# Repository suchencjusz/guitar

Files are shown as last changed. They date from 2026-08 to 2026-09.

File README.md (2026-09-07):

# guitar
My attempts on guitar effects! :D

### tremolo
Actually, the hardest parts were my first encounter with LTspice, and to be precise with ideal mathematical simulations;
as it turns out, building such a circuit with real components doesn't guarantee that it will actually work!
The next reality check came when I tried etching a PCB at home using sodium persulfate, the board turned out fine, but I'm not sure I'd take on that grueling manual task again if I were working with THT components.
The problem with my board was this: there was no ground-plane... It worked, but it picked up noise like the eye of Moscow in Pripyat... Oh, and on top of that, I placed the components incorrectly in KiCad.
I learned more about signal integrity on PCBs and how to do it better, so I redesigned the board and ordered it from a Chinese manufacturer.
After soldering, it worked right away it's never worked this well before. I think I've really learned my lesson about signal integrity on PCBs... the sound is crystal clear.

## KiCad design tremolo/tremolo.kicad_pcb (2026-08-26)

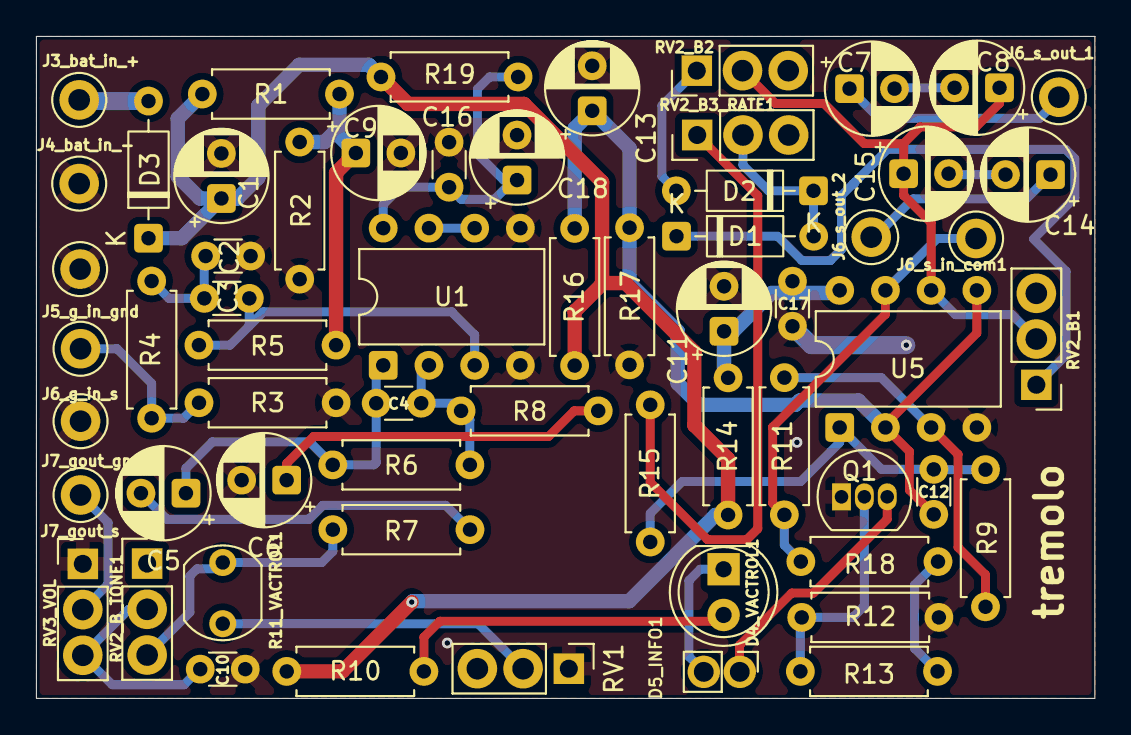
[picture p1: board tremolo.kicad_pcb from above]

Board: 2 copper layers, 58.8 x 36.8 mm, 61 parts (0 on the bottom side), 36 nets.

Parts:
C1: 100u; CP_Radial_D5.0mm_P2.50mm
C2, C4, C12: 100p; C_Disc_D3.0mm_W1.6mm_P2.50mm
C3: 47n; C_Disc_D3.0mm_W1.6mm_P2.50mm
C5, C11, C18: 2.2u; CP_Radial_D5.0mm_P2.50mm
C6: 4.7u; CP_Radial_D5.0mm_P2.50mm
C7, C8: 10u; CP_Radial_D5.0mm_P2.50mm
C9, C13: 47u; CP_Radial_D5.0mm_P2.50mm
C10: 22n; C_Disc_D3.0mm_W1.6mm_P2.50mm
C14, C15: 1u; CP_Radial_D5.0mm_P2.50mm
C16, C17: 100n; C_Disc_D3.0mm_W1.6mm_P2.50mm
D1, D2, D3: 1N914; D_DO-35_SOD27_P7.62mm_Horizontal
D4_VACTROL1: LED; LED_D5.0mm
D5_INFO1: LED; PinHeader_1x02_P2.00mm_Vertical
J3_bat_in_+, J4_bat_in_-, J5_g_in_gnd, J6_g_in_s, J6_s_in_com1, J6_s_out_1, J6_s_out_2, J7_gout_gnd, J7_gout_s: Conn_01x01_Pin; TestPoint_Loop_D2.50mm_Drill1.0mm
Q1: 2N3904; TO-92_Inline
R1, R2, R8, R13, R16, R17: 10k; R_Axial_DIN0207_L6.3mm_D2.5mm_P7.62mm_Horizontal
R3, R5: 1Meg; R_Axial_DIN0207_L6.3mm_D2.5mm_P7.62mm_Horizontal
R4: 1k; R_Axial_DIN0207_L6.3mm_D2.5mm_P7.62mm_Horizontal
R6: 33k; R_Axial_DIN0207_L6.3mm_D2.5mm_P7.62mm_Horizontal
R7, R11: 100k; R_Axial_DIN0207_L6.3mm_D2.5mm_P7.62mm_Horizontal
R9: 220k; R_Axial_DIN0207_L6.3mm_D2.5mm_P7.62mm_Horizontal
R10: 330; R_Axial_DIN0207_L6.3mm_D2.5mm_P7.62mm_Horizontal
R11_VACTROL1: R_Photo; R_LDR_5.1x4.3mm_P3.4mm_Vertical
R12: 3.3k; R_Axial_DIN0207_L6.3mm_D2.5mm_P7.62mm_Horizontal
R14, R19: 100; R_Axial_DIN0207_L6.3mm_D2.5mm_P7.62mm_Horizontal
R15: 33.3k; R_Axial_DIN0207_L6.3mm_D2.5mm_P7.62mm_Horizontal
R18: 4.7k; R_Axial_DIN0207_L6.3mm_D2.5mm_P7.62mm_Horizontal
RV1, RV2_B1, RV2_B2, RV2_B_TONE1: 100k; PinHeader_1x03_P2.54mm_Vertical
RV2_B3_RATE1: 1Meg; PinHeader_1x03_P2.54mm_Vertical
RV3_VOL: 250k; PinHeader_1x03_P2.54mm_Vertical
U1: TL062CP; DIP-8_W7.62mm
U5: LM358P; DIP-8_W7.62mm

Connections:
/4.5V: C9.1, R1.2, R2.1, R5.2
/9V: C1.1, D3.1 (K), R1.1, R10.2, R14.1, R16.2, R19.2
/AUDIO: R7.2, R11_VACTROL1.1, RV2_B_TONE1.3
/GND: C1.2, C2.1, C6.2, C9.2, C10.2, C11.2, C13.2, C16.1, C17.1, C18.2, J4_bat_in_-.1 (Pin_1_1), J5_g_in_gnd.1 (Pin_1_1), J7_gout_gnd.1 (Pin_1_1), Q1.1 (E), R2.2, R3.2, R12.2, R17.2, RV1.1, RV3_VOL.1, U1.4 (VCC-), U1.5 (2IN+), U5.4 (GND)
unnamed: C2.2, C3.2, R4.1
unnamed: C5.2, R7.1
unnamed: C6.1, R8.2
unnamed: C7.2, C8.2
unnamed: C10.1, RV2_B_TONE1.2, RV3_VOL.3
unnamed: C14.2, C15.2
unnamed: D1.2 (A), D2.1 (K), RV2_B3_RATE1.2
unnamed: D1.1 (K), RV2_B1.1
unnamed: D2.2 (A), RV2_B2.1
unnamed: D3.2 (A), J3_bat_in_+.1 (Pin_1_1)
unnamed: D4_VACTROL1.2 (A), R10.1
unnamed: D4_VACTROL1.1 (K), D5_INFO1.2 (A)
unnamed: D5_INFO1.1 (K), Q1.3 (C)
unnamed: J6_g_in_s.1 (Pin_1_1), R3.1, R4.2
unnamed: J6_s_in_com1.1 (Pin_1_1), R11.1, R18.2, U5.7 (2OUT)
unnamed: C7.1, J6_s_out_1.1 (Pin_1_1)
unnamed: C14.1, J6_s_out_2.1 (Pin_1_1)
unnamed: J7_gout_s.1 (Pin_1_1), RV3_VOL.2
unnamed: Q1.2 (B), R12.1, R13.1
unnamed: R11_VACTROL1.2, RV1.2
unnamed: R13.2, R18.1
unnamed: R15.1, RV2_B3_RATE1.1
unnamed: C3.1, R5.1, U1.3 (1IN+)
unnamed: C4.2, R6.2, R8.1, U1.2 (1IN-)
unnamed: C4.1, C5.1, R6.1, U1.1 (1OUT)
unnamed: U1.6 (2IN-), U1.7 (2OUT)
unnamed: C16.2, C18.1, R19.1, U1.8 (VCC+)
unnamed: R9.2, R11.2, U5.3 (1IN+)
unnamed: C12.1, C13.1, R16.1, R17.1, U5.2 (1IN-), U5.5 (2IN+)
unnamed: C12.2, R9.1, R15.2, U5.1 (1OUT)
unnamed: C8.1, C15.1, RV2_B1.2, RV2_B2.2, U5.6 (2IN-)
unnamed: C11.1, C17.2, R14.2, U5.8 (VCC)

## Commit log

2026-08-26 init: tremolo! :D
    [tremolo.kicad_pcb, tremolo.kicad_sch]
2026-08-26 fix: dir
    [tremolo.kicad_pcb, tremolo.kicad_sch]
2026-09-07 Add README with guitar effects project details
    Document experiences and lessons learned while building guitar effects circuits.
